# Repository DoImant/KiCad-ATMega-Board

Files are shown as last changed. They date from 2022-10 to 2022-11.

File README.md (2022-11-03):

# ATMega Board

The usual Arduino boards like the Arduino Uno , Nano, Mini etc. are only conditionally suitable for battery operation.

The current requirement of the built-in LEDs, the USB-UART interface and the quite high quiescent current of the LDO regulator is too high for a longer operation on a battery, even if the microcontroller is in sleep mode.

On the ATMega board only the most necessary components are installed, which are necessary for the operation of a microcontroller. This makes it possible to operate the controller with batteries for a longer time. The screw terminals allow stable and trouble-free connections with external components.

With the help of a jumper the power indicator LED (consumes about 3mA) can be switched on or off as needed. 

## Limitations compared to the usual Arduino boards  

* Programming must be done via the ISP adapter.
* For serial communication an external FTDI adapter is required.
* The analog ports A6 and A7 (e.g. compared to an Arduino Nano) are not available.
* No 3.3V output. But you can use the whole board instead of a 5V LDO with a 3.3V LDO (MCP-1703-3302MB
 or HT7833-1).

## Other technical data

* Usable microcontrollers: ATTiny88, ATmega48A/PA, 88A/PA, 168A/PA, 328/P
* The crystal is exchangeable (depending on the inserted microcontroller max. 20Mhz)
* Supply voltage via JST XH connector or VIN-Pin min. 6V, max. 15V
* Max. 200mA current load (the LDO has a limit of 250mA, the AVR controllers 200mA.)
* Power consumption with an ATMega328P in sleep mode *"SLEEP_MODE_PWR_DOWN"* and disabled ADC < 10µA

## Circuit diagram as PDF file

[Sheet](https://github.com/DoImant/Stuff/blob/main/ATMega-Board/ATMega-Board.pdf)

## The PCB

PCB

3D-Image



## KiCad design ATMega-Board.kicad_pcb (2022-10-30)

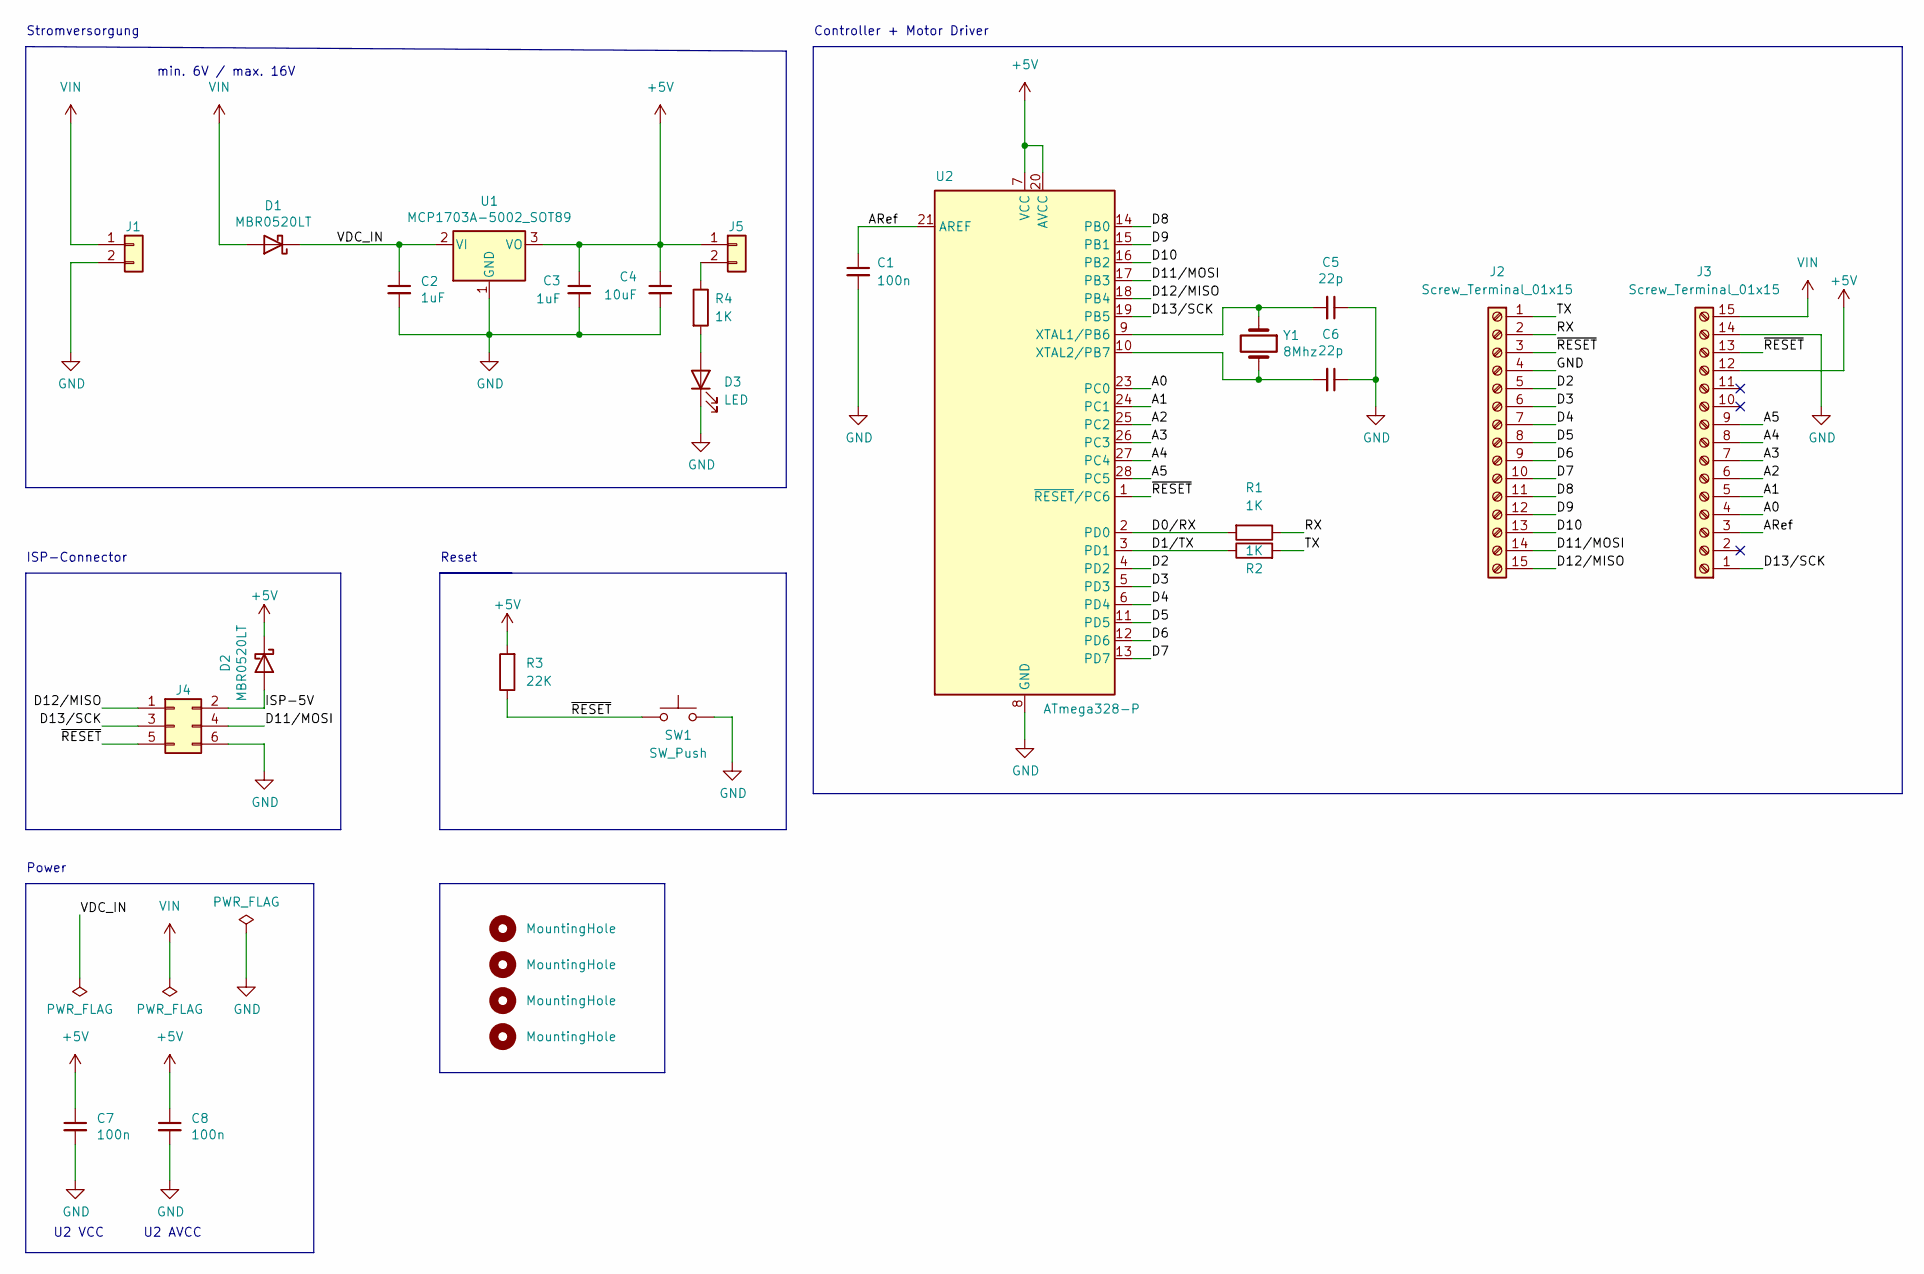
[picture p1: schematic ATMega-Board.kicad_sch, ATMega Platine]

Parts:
C1, C7, C8: 100n; C_0805_2012Metric_Pad1.18x1.45mm_HandSolder
C2, C3: 1uF; C_1206_3216Metric_Pad1.33x1.80mm_HandSolder
C4: 10uF; C_1206_3216Metric_Pad1.33x1.80mm_HandSolder
C5, C6: 22p; C_1206_3216Metric_Pad1.33x1.80mm_HandSolder
D1, D2: MBR0520LT; D_SOD-123
D3: LED; LED_1206_3216Metric_Pad1.42x1.75mm_HandSolder
H1, H2, H3, H4: MountingHole; MountingHole_3.2mm_M3_DIN965
J1: Conn_01x02; JST_XH_S2B-XH-A-1_1x02_P2.50mm_Horizontal
J2, J3: Screw_Terminal_01x15; TerminalBlock_Phoenix_PT-1,5-15-5.0-H_1x15_P5.00mm_Horizont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
J4: Conn_02x03_Odd_Even; IDC-Header_2x03_P2.54mm_Vertical
J5: Conn_01x02; PinHeader_1x02_P2.54mm_Vertical
R1, R2, R4: 1K; R_1206_3216Metric_Pad1.30x1.75mm_HandSolder
R3: 22K; R_1206_3216Metric_Pad1.30x1.75mm_HandSolder
SW1: SW_Push; SW_SPST_T931x
U1: MCP1703A-5002_SOT89; SOT-89-3
U2: ATmega328-P; DIP-28_W7.62mm_Socket_LongPads
Y1: 8Mhz; Crystal_HC49-4H_Vertical

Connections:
+5V: C3.1, C4.1, C7.1, C8.1, D2.1 (K), J3.12, J5.1, R3.2, U1.3 (VO), U2.7 (VCC), U2.20 (AVCC)
/A0: J3.4, U2.23 (PC0)
/A1: J3.5, U2.24 (PC1)
/A2: J3.6, U2.25 (PC2)
/A3: J3.7, U2.26 (PC3)
/A4: J3.8, U2.27 (PC4)
/A5: J3.9, U2.28 (PC5)
/ARef: C1.1, J3.3, U2.21 (AREF)
/D0/RX: R1.2, U2.2 (PD0)
/D1/TX: R2.1, U2.3 (PD1)
/D2: J2.5, U2.4 (PD2)
/D3: J2.6, U2.5 (PD3)
/D4: J2.7, U2.6 (PD4)
/D5: J2.8, U2.11 (PD5)
/D6: J2.9, U2.12 (PD6)
/D7: J2.10, U2.13 (PD7)
/D8: J2.11, U2.14 (PB0)
/D9: J2.12, U2.15 (PB1)
/D10: J2.13, U2.16 (PB2)
/D11/MOSI: J2.14, J4.4, U2.17 (PB3)
/D12/MISO: J2.15, J4.1, U2.18 (PB4)
/D13/SCK: J3.1, J4.3, U2.19 (PB5)
/ISP-5V: D2.2 (A), J4.2
/RX: J2.2, R1.1
/TX: J2.1, R2.2
/VDC_IN: C2.1, D1.1 (K), U1.2 (VI)
/~RESET: J2.3, J3.13, J4.5, R3.1, SW1.1, U2.1 (~RESET/PC6)
GND: C1.2, C2.2, C3.2, C4.2, C5.1, C6.1, C7.2, C8.2, D3.1 (K), J1.2, J2.4, J3.14, J4.6, SW1.2, U1.1 (GND), U2.8 (GND), U2.22 (GND); also elsewhere on the board
unnamed: C5.2, U2.9 (XTAL1/PB6), Y1.1
unnamed: C6.2, U2.10 (XTAL2/PB7), Y1.2
unnamed: D3.2 (A), R4.2
unnamed: J5.2, R4.1
VIN: D1.2 (A), J1.1, J3.15; also elsewhere on the board

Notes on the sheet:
Controller + Motor Driver
min. 6V / max. 16V
Power
Stromversorgung
U2 AVCC
ISP-Connector
U2 VCC
Reset

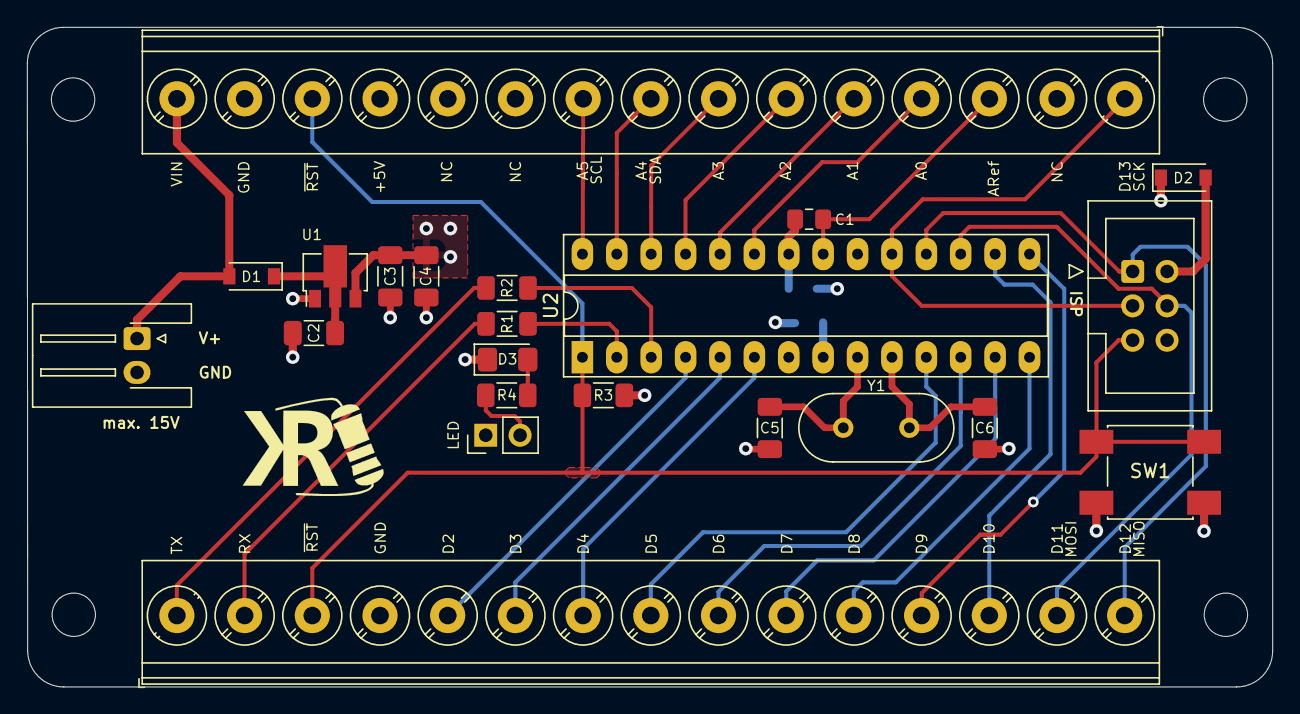
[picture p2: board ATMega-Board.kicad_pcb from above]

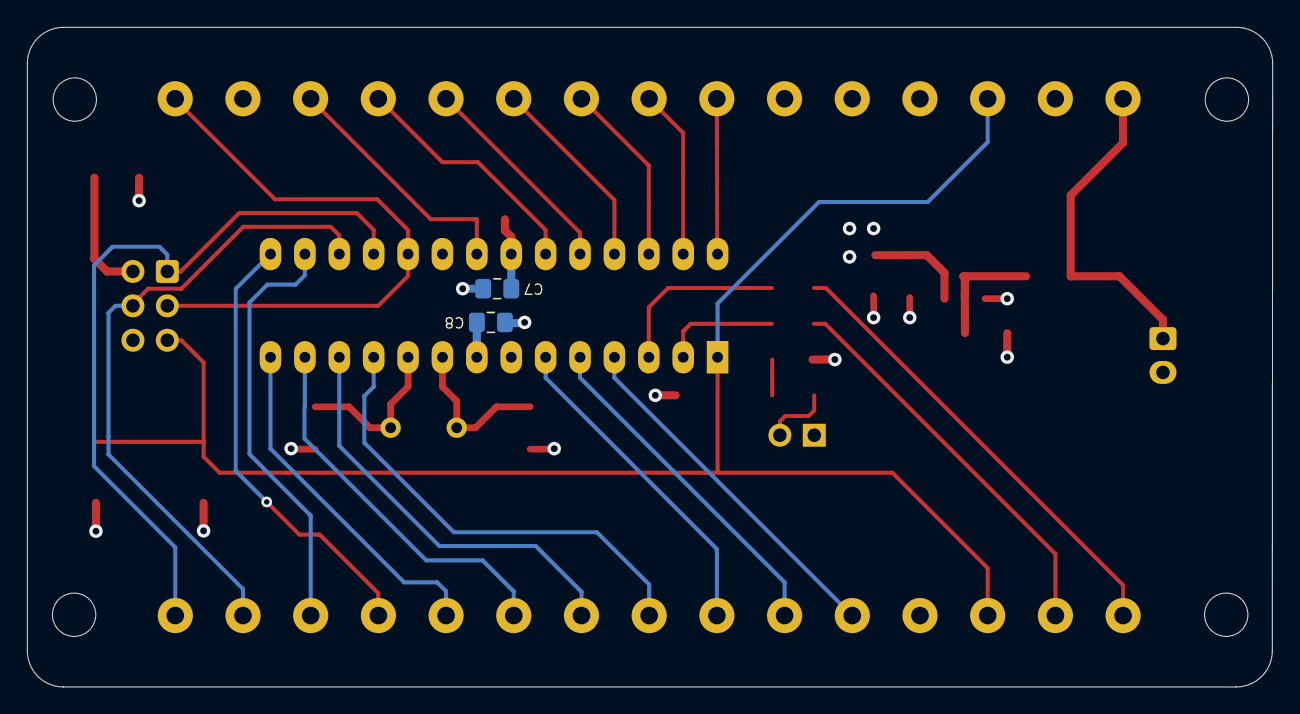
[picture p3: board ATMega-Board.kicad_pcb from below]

Board: 4 copper layers, 92.0 x 48.7 mm, 28 parts (2 on the bottom side), 33 nets.

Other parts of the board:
locked: Conn_01x02; JST_XH_S2B-XH-A-1_1x02_P2.50mm_Horizontal

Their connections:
GND: locked.2; also elsewhere on the board
VIN: locked.1; also elsewhere on the board
